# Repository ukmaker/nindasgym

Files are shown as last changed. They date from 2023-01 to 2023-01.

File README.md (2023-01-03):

# nindasgym
A 3D printed gym with flashing lights, music and animation

All the gym equipment was printed from [TanyaAkinora's project](https://www.instructables.com/3d-Printed-Tiny-Gym/) - thanks Tanya!

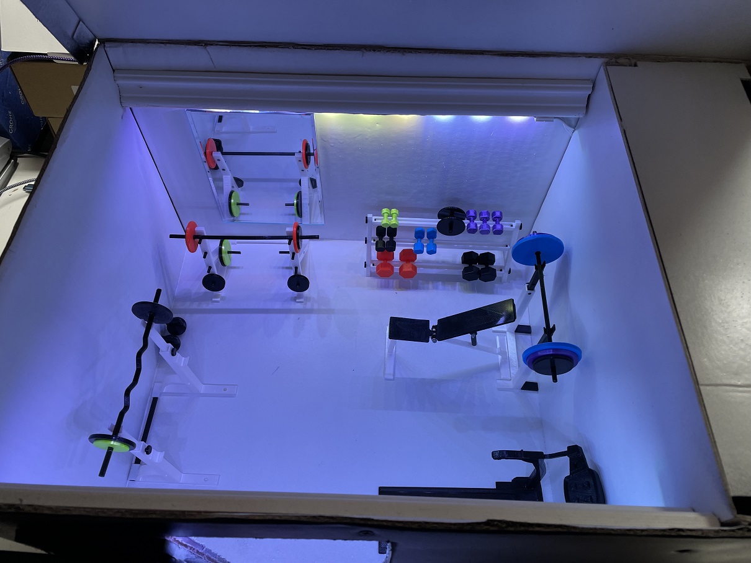
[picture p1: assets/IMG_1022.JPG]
The End Result (https://youtube.com/watch?v=ekH63PJm3gI)

In Action

# A Reasonable Excuse
Why do something this silly? Hmm?

The story goes something like this:
  - The Dutch celebrate SinterKlaas on the 5th December as part of their Christmas tradition
  - One of the components of the celebrationis that there is a party
  - Each guest gets assigned (randomly and without the other knowing) another guest
  - The guests then make by hand a small suprise, write an accompanying poem and buy a small present
  - On the 5th, the recipients read their poem and receive their surprise and present
  - I know this because my Dutch neighbour told me, so it must be true
  - This was the second year for us to copy the tradition here in the UK
  - We may have gone a tiny bit overboard

My surprise recipient this year was my friend's sister Ninda who is a personal trainer. I started just with a cardboard box and the 3d printed gym equipment. Then I noticed I had a spare strip of 3-colour LEDS.......

# How Can I Make One?

1. Print the gym bits from Tetiana's project
2. Add extra ingredients
3. Bake until done

# The Recipe
## Ingredients
1. Tetiana's gym equipment
2. A cardboard box
3. Spray paint
4. 3-colour LED lighting strip - lengths to suit your box
5. A suitable power supply. I ended up using an 18V, 2A supply to make sure the stepper motor had enough oomph
6. A stepper motor. You'll need to experiment
7. One Arduino - pretty much anything will do
8. One stepper motor driver - [e.g. this A4988 one](https://reprapworld.co.uk/electronics/3d-printer-modules/stepper-drivers/a4988-stepper-motor-driver-carrier/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)
9. One [MP3 player module](https://www.amazon.co.uk/dp/B01N6P237G/ref=pe_27063361_485629781_TE_item)
10.  A small loudspeaker
11. A handful of components as per the schematic
12. You favourite protoyping board
13. Assorted bits of hardware for the lifting mechanism - e.g. small drawer slide, GT2 drive belt, pulley wheels.... 

## Method - Electronics
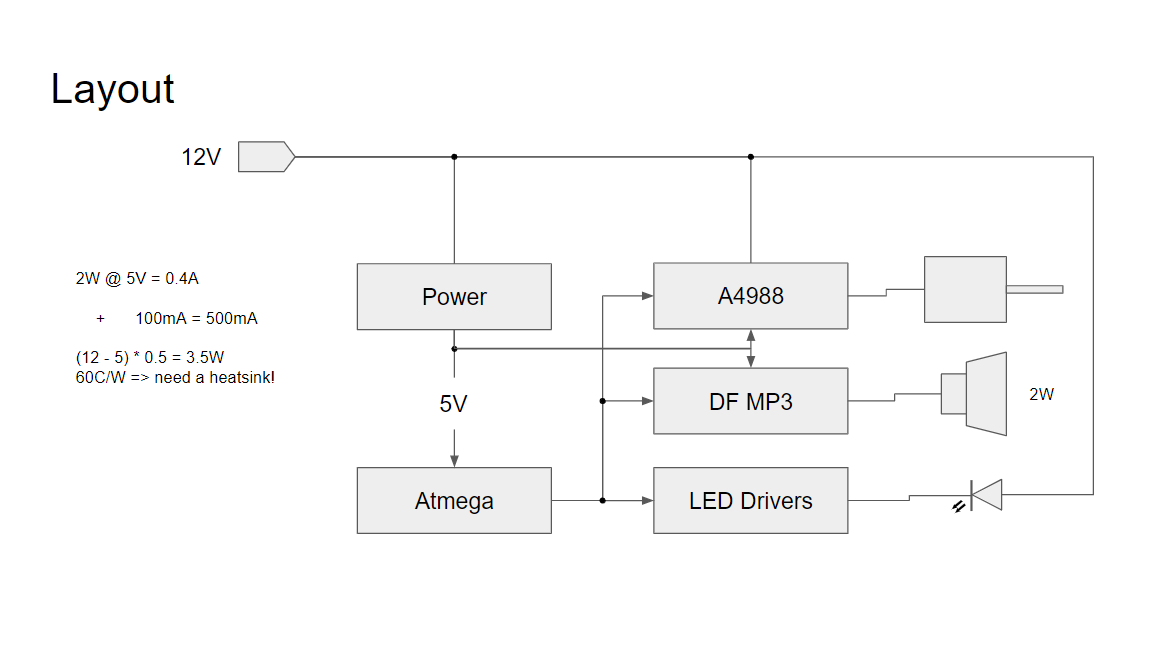
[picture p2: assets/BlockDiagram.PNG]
Block Diagram

If you look at all the photos in the assets/ folder you'll see that I constructed the electronics on several small boards for ease of debugging:
 - A board holding the Atmega328 and associated support components. You can replace this directly with an Arduino if you like. I just happen to have a load of 328Ps and crystals etc, so it's cheap and easy for me to do this. I put the MP3 player
 module on this board also
 - A board holding the 7805 regulator and the LED driver transistors. I used ZTX650 transistors because I've had a box of them I'm been slowly getting through since 1980. You can use something more modern like ZTX618 or even 2N7000 (add 100K pull-downs on the gate if you do this).
 - A board holding the A4988 stepper driver

## Method - Mechanics
There was no method. I bodged stuff together until it worked. I had to swap the 12V power supply I was using for an 18V supply
literally at the last minute because the stepper just didn't have the power to lift the lid.

If I was to do this again (stop tittering in the back) I'd actually design it. There would be appropriate gearing.
Vital pieces of mechnanics would be properly attached, not held on with superglue/hotglue/screws through cardboard.

The MCU knows when to stop raising or lowering the lid because there are two microswitches, one at the top of the box and one near the bottom. I 3D printed a T-shaped attachemnt which is stuck to the drive belt and triggers the microswitches. If you look at the image TopEndstop.jpg you will see the wire going to the microswitch which is glued to a 3D printed bracket which is itself stuck to the the side of the box.

## Method - Firmware
I bought a CD copy of the Survivor album, ripped the Eye of the Tiger track and copied it to an SD card which goes in the MP3 player. The CD was part of Ninda's present.

I carefully timed how long it takes to get to the lyric "rising up" and programmed that into the Arduino sketch.

The sketch is triggered when the door is opened because there is a small microswitch which is activated when the door opens.

Closing the door causes the music to stop, the lights stop flashing and glow red and the lid goes back down.

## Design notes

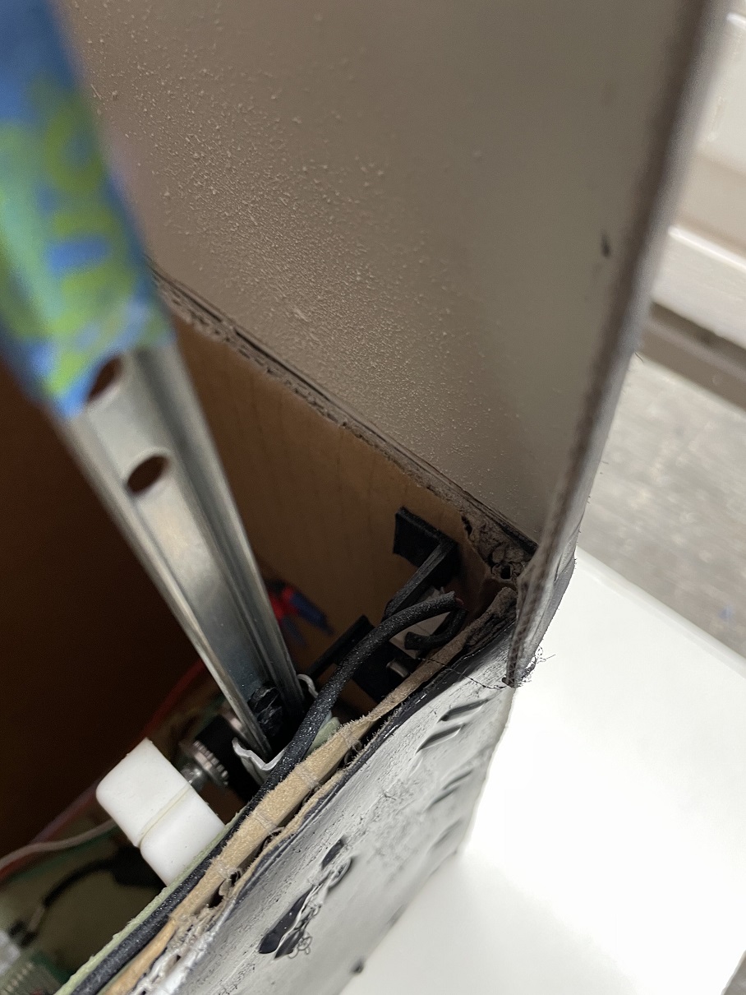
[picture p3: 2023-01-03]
assets/TopEndstop.jpg

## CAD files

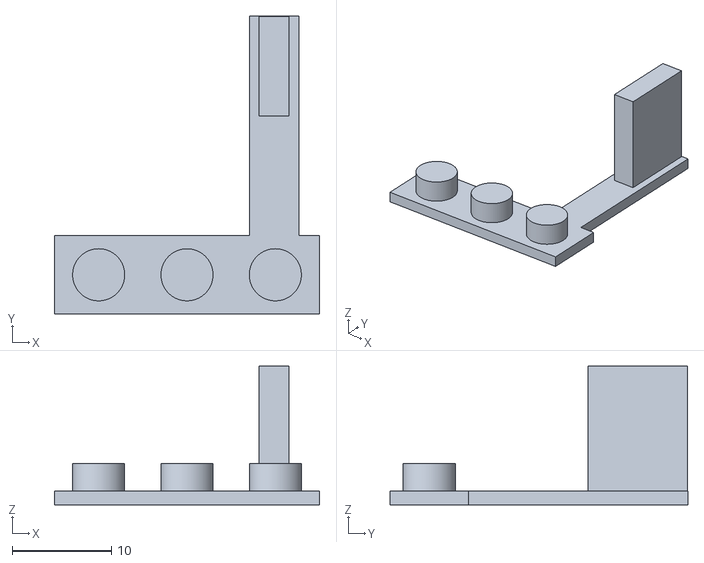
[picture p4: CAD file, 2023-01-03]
Gym/EndStop.stl
26.7 x 30.0 x 14.0

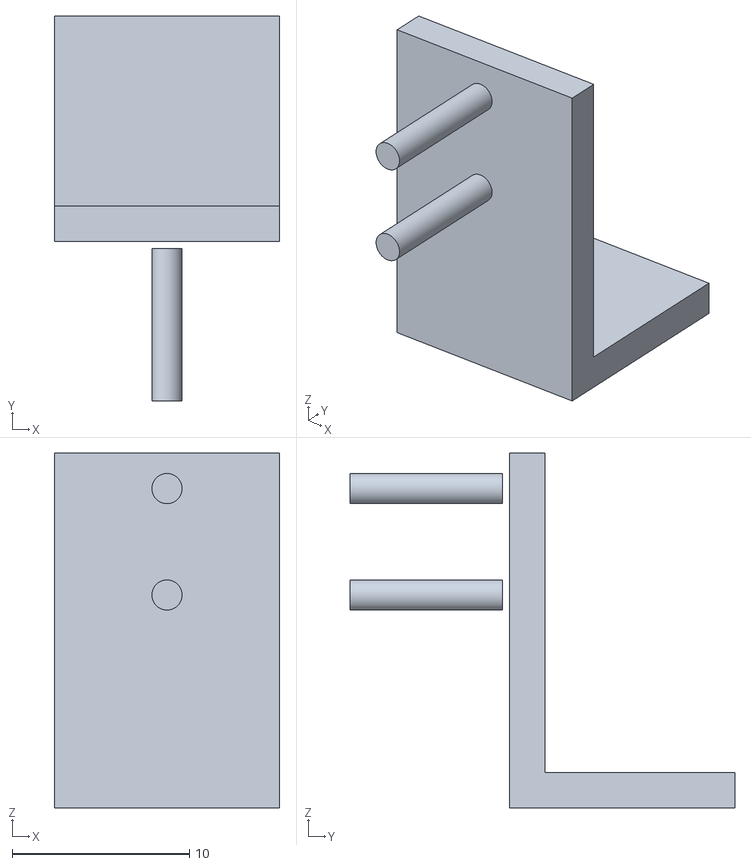
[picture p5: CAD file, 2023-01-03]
Gym/MicroswitchMount.stl
12.7 x 21.7 x 20.0

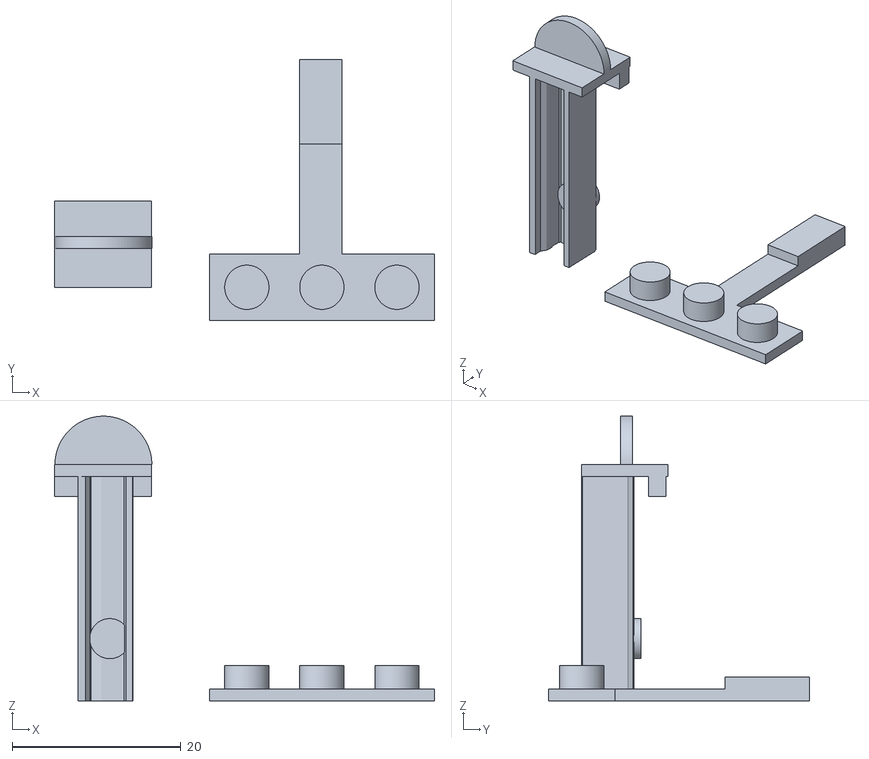
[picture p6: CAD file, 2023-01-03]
Gym/Both.stl
45.0 x 30.9 x 33.8

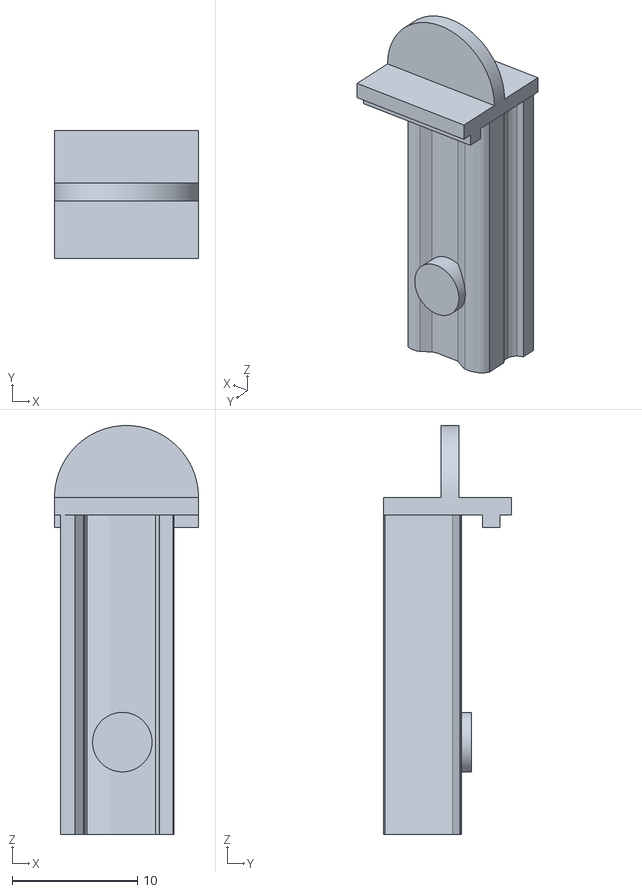
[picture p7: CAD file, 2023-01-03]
Gym/RailEnd.stl
11.5 x 10.2 x 32.7

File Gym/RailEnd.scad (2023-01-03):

/**
* Plastic insert to snap into the end offset* the
* drawer slide for Ninda's Gym
**/


$fn=100;

hole_dia = 5.25;
hole_edge_from_end = 16.5;
rail_width = 11.5;
rail_width_inner = 6.5;
rail_depth = 6;
rail_thickness = 1.4;

cap_dia = rail_width;

cap_inner_length = hole_edge_from_end + 2*hole_dia;
cap_length = cap_inner_length + cap_dia / 2;

hole_spacing = 14.15 - hole_dia;

module half_circle(dia, thickness) {

difference() {
cylinder(h = thickness, d = dia);

translate([-(dia+1)/2,-dia,-thickness/2])
cube([dia+1, dia, thickness*2]);

}

}


module rail_inner() {
scale([6.5/10.7,1,1])
linear_extrude(height = cap_inner_length)
polygon([
[0,0],
[0,0.7],
[0,1.4],
[0.3,1.5],
[0.6,1.6],
[0.75,1.75],
[0.9,1.9],
[1,2.1],
[1.1,2.3],
[1.1,2.55],
[1.1,2.8],
[1,2.95],
[0.9,3.1],
[0.8,3.3],
[0.8,4.25],
[0.8,5.2],
[1.1,5.6],
[1.4,5.8],
[2,6],
[2.5,6.1],
[3.1,6.1],
[3.4,6],
[4.6,5.4],
[7.2,5.4],
[7.8,5.5],
[8.8,6.1],
[9.05,6.15],
[9.3,6.2],
[9.9,6.2],
[10.1,6.15],
[10.3,6.1],
[10.4,6],
[10.55,5.75],
[10.7,5.5],
[10.6,0.1],
[9.3,0.1],
[9.3,3.78],
[9.25,4.03],
[8.95,4.34],
[8.7,4.4],
[4.6,4.4],
[2.9,4.65],
[2.5,4.7],
[2.2,4.5],
[2.1,3.3],
[2.3,2.9],
[2.3,2.5],
[2.2,1.9],
[1.4,1.2],
[1.4,0.1],
[0.7,0.05],
[0,0]]);

translate([rail_width/2 - 2,rail_depth - rail_thickness - 0.4,cap_inner_length - hole_dia/2 - hole_edge_from_end - 0.5])
rotate([-90,0,0])
cylinder(h=2 * rail_thickness, d=hole_dia - 0.5);

// now stick a half-circle on the top on a square base
translate([ - 2 * rail_thickness,0,cap_inner_length - 0.4]){
cube([rail_width, rail_depth + 3 * rail_thickness, rail_thickness]);

translate([0,rail_depth + rail_thickness+0.5,-2 * rail_thickness+0.4])
cube([rail_width, rail_thickness*1.5,rail_thickness*2]);
}

translate([3 ,rail_depth,cap_inner_length+rail_thickness-0.4])
rotate([90,0,0])
half_circle(rail_width, rail_thickness);
}

module end_stop() {
// three snap-ins with a rod sticking out

cylinder(h=3 * rail_thickness, d = hole_dia);
translate([hole_spacing,0,0])
cylinder(h=3 * rail_thickness, d = hole_dia);
translate([2 * hole_spacing,0,0])
cylinder(h=3 * rail_thickness, d = hole_dia);

translate([-hole_spacing/2,-0.75 * hole_dia,0])
cube([3 * hole_spacing, 1.5 * hole_dia, rail_thickness]);

// sticky-out bit
translate([2 * hole_spacing - hole_dia/2,-0.75 * hole_dia,0])
cube([5,30,rail_thickness]);

translate([2 * hole_spacing - hole_dia/2 + 1,16,0])
cube([3,10,10 *rail_thickness]);
}

module microswitch_mount() {
w = 12.7;
d = 5.6;
h = 6.5;
terminal_length = 6;
mount_to_roller = 20;
hole_dia = 2;
hole_spacing = 6;
// Flat base which can be glued on
cube([w,w,2]);
//side panel with sticky out bits to snap the switch on to
cube([w,2,20]);
//sticky out bit

translate([w/2,-0.4,12])
rotate([90,0,0])
cylinder(h=d + 3, d=hole_dia - 0.3);

translate([w/2, -0.4, 12 + hole_spacing])
rotate([90,0,0])
cylinder(h=d + 3, d=hole_dia - 0.3);
}


microswitch_mount();

//rail_inner();

//translate([20,0,0])end_stop();

//half_circle(rail_width, rail_thickness);

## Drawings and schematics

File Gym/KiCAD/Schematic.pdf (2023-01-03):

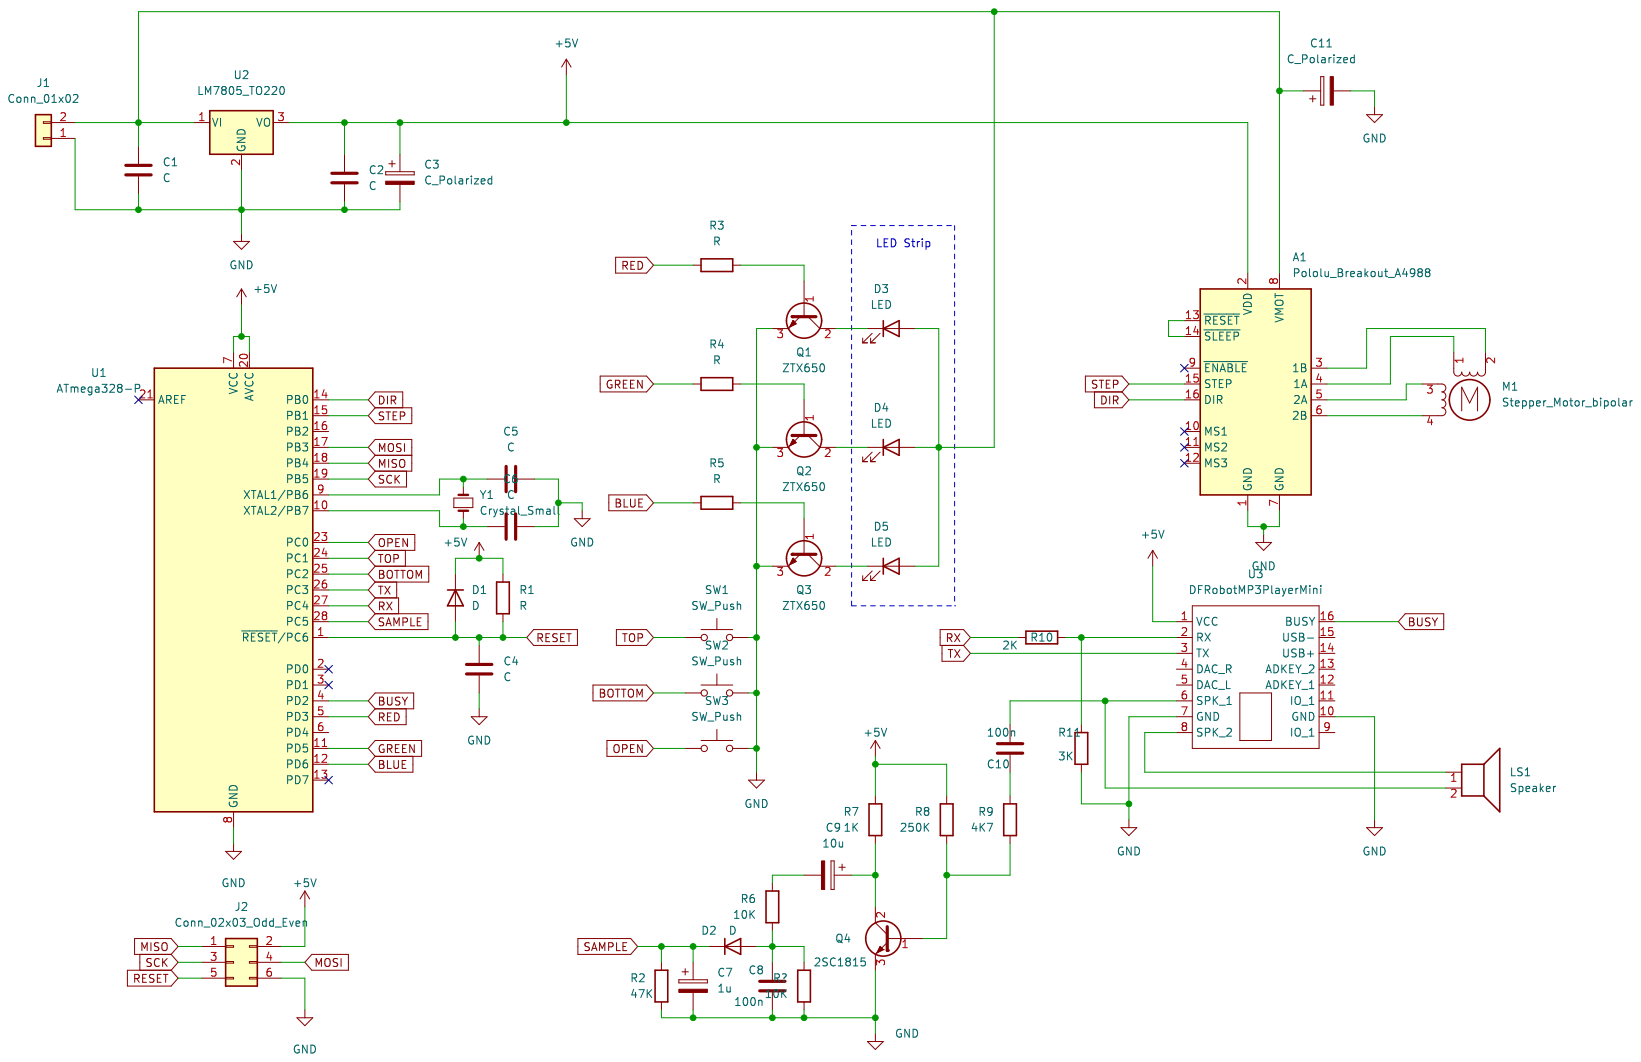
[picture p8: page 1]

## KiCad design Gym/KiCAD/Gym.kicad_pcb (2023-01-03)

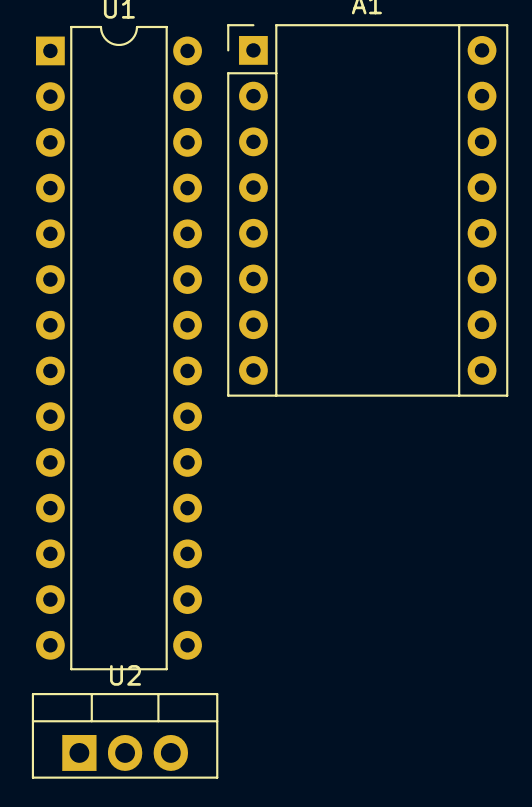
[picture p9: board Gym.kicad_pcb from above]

Board: 2 copper layers, 3 parts (0 on the bottom side), 6 nets, no tracks yet.

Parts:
A1: Pololu_Breakout_A4988; Pololu_Breakout-16_15.2x20.3mm
U1: ATmega328-P; DIP-28_W7.62mm
U2: LM7805_TO220; TO-220-3_Vertical

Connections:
+5V: A1.2 (VDD), U1.7 (VCC), U1.20 (AVCC), U2.3 (VO)
DIR: A1.16 (DIR), U1.14 (PB0)
GND: A1.1 (GND), A1.7 (GND), U1.8 (GND), U1.22 (GND), U2.2 (GND)
unnamed: A1.8 (VMOT), U2.1 (VI)
unnamed: A1.13 (~RESET), A1.14 (~SLEEP)
STEP: A1.15 (STEP), U1.15 (PB1)

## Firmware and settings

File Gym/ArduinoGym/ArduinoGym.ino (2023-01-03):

/***************************************************
DFPlayer - A Mini MP3 Player For Arduino
 <https://www.dfrobot.com/product-1121.html>
 
 ***************************************************
 This example shows the basic function of library for DFPlayer.
 
 Created 2016-12-07
 By [Angelo qiao](Angelo.qiao@dfrobot.com)
 
 GNU Lesser General Public License.
 See <http://www.gnu.org/licenses/> for details.
 All above must be included in any redistribution
 ****************************************************/

/***********Notice and Trouble shooting***************
 1.Connection and Diagram can be found here
 <https://www.dfrobot.com/wiki/index.php/DFPlayer_Mini_SKU:DFR0299#Connection_Diagram>
 2.This code is tested on Arduino Uno, Leonardo, Mega boards.
 ****************************************************/

#include "Arduino.h"
#include "SoftwareSerial.h"
#include "DFRobotDFPlayerMini.h"

// Blue wire is DIR, Green is STEP
#define DIR_PIN 8
#define STEP_PIN 9
#define STEP_DELAY_MS 6

#define MP3_TX_PIN A4
#define MP3_RX_PIN A3

#define OPEN_PIN A0
#define TOP_PIN A1
#define BOTTOM_PIN A2

#define SAMPLE_PIN A5
#define BUSY_PIN 2

#define RED_PIN 3
#define GREEN_PIN 5
#define BLUE_PIN 6

#define LED_PIN 7

#define DOOR_CLOSED 0
#define DOOR_OPEN 2

#define LID_CLOSED 0
#define LID_RAISING 1
#define LID_OPEN 2
#define LID_LOWERING 3

// milliseconds until the line "Rising up..."
#define RISING_UP 50000

uint8_t door;
uint8_t lid;
unsigned long time;
uint8_t stepDiv;

SoftwareSerial mySoftwareSerial(MP3_RX_PIN, MP3_TX_PIN);  // RX, TX
DFRobotDFPlayerMini myDFPlayer;
void printDetail(uint8_t type, int value);


void openLid() {
Serial.println("openLid");
           step(true);
}

void closeLid() {
 Serial.println("closeLid");
          step(false);
}

void step(bool up) {
  stepDiv++;
  if(stepDiv < 10) return;
  stepDiv = 0;
  digitalWrite(DIR_PIN, up ? LOW : HIGH);
  digitalWrite(STEP_PIN, HIGH);
  delay(STEP_DELAY_MS);
  digitalWrite(STEP_PIN, LOW);
  delay(STEP_DELAY_MS);
}

void setup() {

  Serial.begin(115200);

  pinMode(TOP_PIN, INPUT_PULLUP);
  pinMode(BOTTOM_PIN, INPUT_PULLUP);
  pinMode(OPEN_PIN, INPUT_PULLUP);
  pinMode(BUSY_PIN, INPUT);
  pinMode(RED_PIN, OUTPUT);
  pinMode(GREEN_PIN, OUTPUT);
  pinMode(BLUE_PIN, OUTPUT);
  pinMode(STEP_PIN, OUTPUT);
  pinMode(DIR_PIN, OUTPUT);
  pinMode(LED_PIN, OUTPUT);
  digitalWrite(LED_PIN,1);
  delay(1000);
  digitalWrite(LED_PIN,0);
  delay(200);
  digitalWrite(LED_PIN,1);
  delay(200);
  digitalWrite(LED_PIN,0);
  delay(200);
  digitalWrite(LED_PIN,1);

  // wait to give the MP3 player time to initialize
  delay(3000);

  mySoftwareSerial.begin(9600);
  
  door = DOOR_CLOSED;
  lid = LID_CLOSED;
  time = millis();
  stepDiv = 0;

  Serial.println();
  Serial.println(F("DFRobot DFPlayer Mini Demo"));
  Serial.println(F("Initializing DFPlayer ... (May take 3~5 seconds)"));

  if (!myDFPlayer.begin(mySoftwareSerial)) {  //Use softwareSerial to communicate with mp3.
    Serial.println(F("Unable to begin:"));
    Serial.println(F("1.Please recheck the connection!"));
    Serial.println(F("2.Please insert the SD card!"));
    while (true) {
    delay(200);
  digitalWrite(LED_PIN,0);
  delay(200);
  digitalWrite(LED_PIN,1);
    }
  }
  Serial.println(F("DFPlayer Mini online."));
  myDFPlayer.volume(28);  //Set volume value. From 0 to 30
  myDFPlayer.EQ(5);
}

void loop() {

  if (digitalRead(OPEN_PIN) == 0) {
    if (door == DOOR_CLOSED) {
      door = DOOR_OPEN;
      myDFPlayer.play(1);  //Play the first mp3
      time = millis();
      lid = LID_CLOSED;
      Serial.println("Door opened");
    }

    if (door == DOOR_OPEN) {
      long volume = map(analogRead(SAMPLE_PIN), 0, 256, 0, 255);
      analogWrite(RED_PIN, volume);
      analogWrite(GREEN_PIN, volume);
      analogWrite(BLUE_PIN, volume);
    }

    if (door == DOOR_OPEN && (millis() - time) > RISING_UP) {
      if (lid == LID_CLOSED) {
        Serial.println("Start raising lid");
        lid = LID_RAISING;
      }
      if (lid == LID_RAISING) {
        if (digitalRead(TOP_PIN) == 0) {
         Serial.println("Raising lid");
         openLid();
        } else {
        Serial.println("Lid raised");
           lid = LID_OPEN;
        }
      }
      if(lid == LID_OPEN && digitalRead(BUSY_PIN)) {
        // Song is over
        analogWrite(RED_PIN, 255);
        analogWrite(GREEN_PIN, 255);
        analogWrite(BLUE_PIN, 255);
      }
    }
  } else {
    if (door == DOOR_OPEN) {
      door = DOOR_CLOSED;
      myDFPlayer.stop();
      Serial.println("Door closed");
      lid = LID_LOWERING;
      analogWrite(RED_PIN, 255);
      analogWrite(GREEN_PIN, 0);
      analogWrite(BLUE_PIN, 0);
    }

    if (lid == LID_LOWERING) {
      Serial.println("Lowering lid");
      if (digitalRead(BOTTOM_PIN) == 0) {
        closeLid();

      } else {
        analogWrite(RED_PIN, 0);
        lid = LID_CLOSED;
      }
    }
  }

  if (myDFPlayer.available()) {
    printDetail(myDFPlayer.readType(), myDFPlayer.read());  //Print the detail message from DFPlayer to handle different errors and states.
  }
}

void printDetail(uint8_t type, int value) {
  switch (type) {
    case TimeOut:
      Serial.println(F("Time Out!"));
      break;
    case WrongStack:
      Serial.println(F("Stack Wrong!"));
      break;
    case DFPlayerCardInserted:
      Serial.println(F("Card Inserted!"));
      break;
    case DFPlayerCardRemoved:
      Serial.println(F("Card Removed!"));
      break;
    case DFPlayerCardOnline:
      Serial.println(F("Card Online!"));
      break;
    case DFPlayerUSBInserted:
      Serial.println("USB Inserted!");
      break;
    case DFPlayerUSBRemoved:
      Serial.println("USB Removed!");
      break;
    case DFPlayerPlayFinished:
      Serial.print(F("Number:"));
      Serial.print(value);
      Serial.println(F(" Play Finished!"));
      break;
    case DFPlayerError:
      Serial.print(F("DFPlayerError:"));
      switch (value) {
        case Busy:
          Serial.println(F("Card not found"));
          break;
        case Sleeping:
          Serial.println(F("Sleeping"));
          break;
        case SerialWrongStack:
          Serial.println(F("Get Wrong Stack"));
          break;
        case CheckSumNotMatch:
          Serial.println(F("Check Sum Not Match"));
          break;
        case FileIndexOut:
          Serial.println(F("File Index Out of Bound"));
          break;
        case FileMismatch:
          Serial.println(F("Cannot Find File"));
          break;
        case Advertise:
          Serial.println(F("In Advertise"));
          break;
        default:
          break;
      }
      break;
    default:
      break;
  }
}

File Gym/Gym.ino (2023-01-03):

/*Example sketch to control a stepper motor with A4988 stepper motor driver and Arduino without a library. More info: https://www.makerguides.com */

// Blue wire is DIR, Green is STEP
#define DIR_PIN 8
#define STEP_PIN 9
#define STEP_DELAY_MS 6

// green red blue yellow

#define RED_PIN 3
#define GREEN_PIN 5
#define BLUE_PIN 6

void step(bool up) {
    digitalWrite(DIR_PIN, up ? HIGH : LOW);
    digitalWrite(STEP_PIN, HIGH);
    delay(STEP_DELAY_MS);
    digitalWrite(STEP_PIN, LOW);
    delay(STEP_DELAY_MS);
}

void setup() {
  // Declare pins as output:
  pinMode(STEP_PIN, OUTPUT);
  pinMode(DIR_PIN, OUTPUT);
  pinMode(RED_PIN, OUTPUT);
  pinMode(GREEN_PIN, OUTPUT);
  pinMode(BLUE_PIN, OUTPUT);
}

void loop() {
  // Fade each colour up one by one
  analogWrite(RED_PIN,0);    
  analogWrite(GREEN_PIN,0);    
  analogWrite(BLUE_PIN,0);
      
  for(int i=0; i< 256; i++) {
    analogWrite(RED_PIN,i);
    delay(5);
    step(true);
  }
  for(int i=0; i< 256; i++) {
    analogWrite(GREEN_PIN,i);
    delay(5);
    step(false);
  }
  for(int i=0; i< 256; i++) {
    analogWrite(BLUE_PIN,i);
    delay(5);
  }
}

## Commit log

2023-01-03 Initial import
    [Both.stl, EndStop.stl, Gym.kicad_pcb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]
2023-01-03 Added schematic PDF and renamed the parent folder
    [Gym.kicad_pcb, Gym.kicad_sch]
